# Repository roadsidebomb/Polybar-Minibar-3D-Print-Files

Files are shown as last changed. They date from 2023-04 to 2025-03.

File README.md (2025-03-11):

<br/>
<div align="center">
Polybar & Minibar
</div>

# Polybar & Minibar
**3D Printable Music Game Controllers!**

The Polybar project, by 3PCS (threepieces), is a modular 3D printable controller for music games like YARG, Clone Hero, or similar.
  
You can find the latest version under [releases](https://github.com/roadsidebomb/Polybar-Minibar-3D-Print-Files/releases). The download includes all STL, F3D and PCB files for use under the license listed below.

## 🎧 Discord 

<p>Join us on Discord! https://discord.gg/rRTbyKxyRu<br /> 
If you have questions regarding downloads, editing of files or need help with assembling your controller, drop us a line. We won't bite!</p>

## 🔨 Contributing

<p>Contributions are always welcome!<br /> 
If you have ideas for a new project, or existing ones, feel free to add roadsidebomb#7604 on Discord to get in touch on how to get involved.</p>

## 💎 License

<p>This project utilizes the Attribution-NonCommercial-ShareAlike 4.0 International (CC BY-NC-SA 4.0) license.<br /> 
https://creativecommons.org/licenses/by-nc-sa/4.0/<br /> 
You are free to:<br /> 
Share — copy and redistribute the material in any medium or format<br /> 
Adapt — remix, transform, and build upon the material<br /> 
Under no circumstances are you allowed to use any of the provided materials for commercial works, unless given permission by the owner.</p>

## 💸 Donate

<p>You can donate to 3PCS, and support projects like this, and future projects at the link below!<br /> 
https://ko-fi.com/threepcs</p>

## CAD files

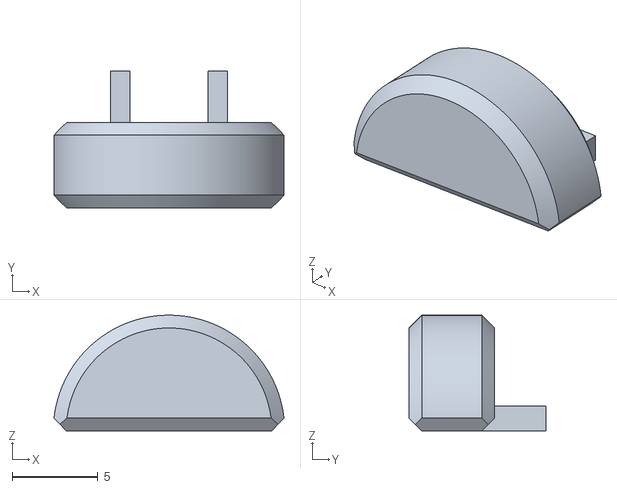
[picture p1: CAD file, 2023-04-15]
Official Releases/Polybar-Minibar v5.0 STLs/Alternates/1. Kailh Choc Fret Insert/Kailh Choc Fret Insert - .25 down.stl
13.4 x 8.00 x 6.75

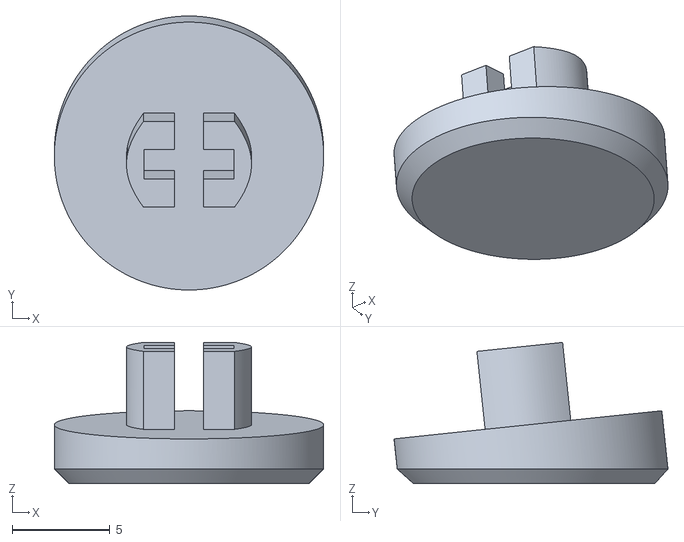
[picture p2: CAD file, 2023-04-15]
Official Releases/Polybar-Minibar v5.0 STLs/Alternates/2. MX Cherry Fret Insert/MX Cherry Fret Insert - .5 down.stl
13.8 x 14.0 x 7.21

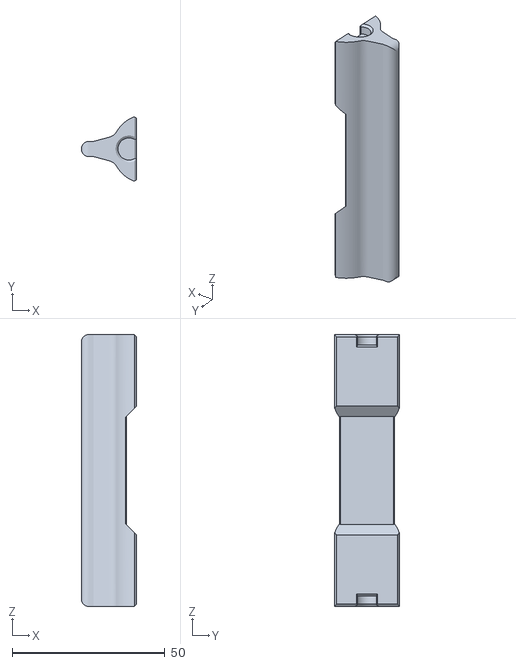
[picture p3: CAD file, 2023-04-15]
Official Releases/Polybar-Minibar v5.0 STLs/Alternates/3. Large Strum Bar/Large Strum Bar - 1 up.stl
18.1 x 21.1 x 89.0

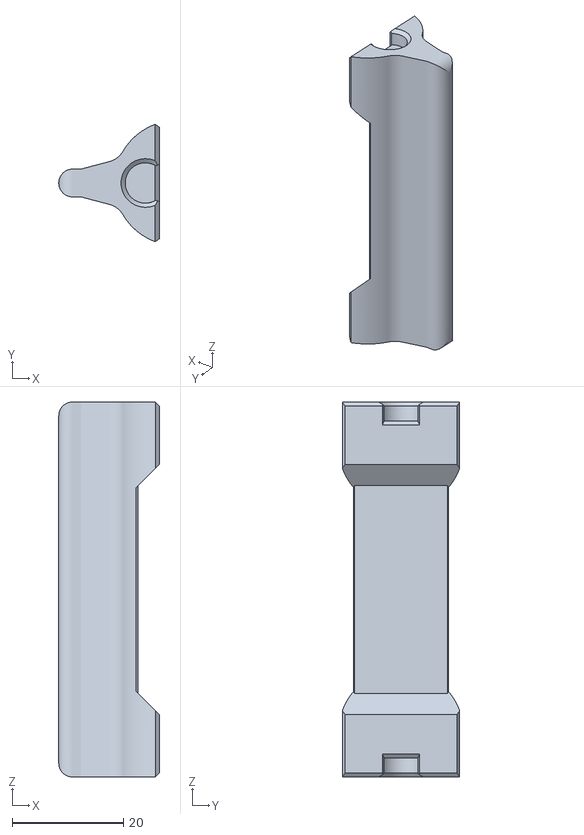
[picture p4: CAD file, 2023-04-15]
Official Releases/Polybar-Minibar v5.0 STLs/Alternates/4. Small Strum Bar/Small Strum Bar - .5 up.stl
18.1 x 21.1 x 67.5

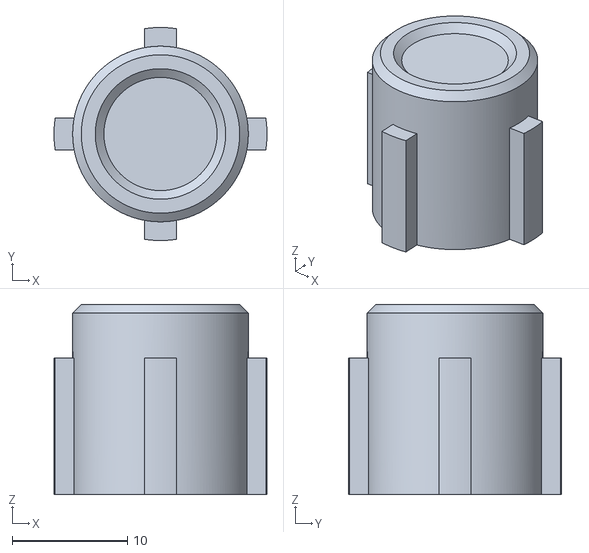
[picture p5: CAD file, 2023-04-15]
Official Releases/Polybar-Minibar v5.0 STLs/Alternates/5. Large Button/Large Button - .375 down.stl
18.5 x 18.5 x 16.5

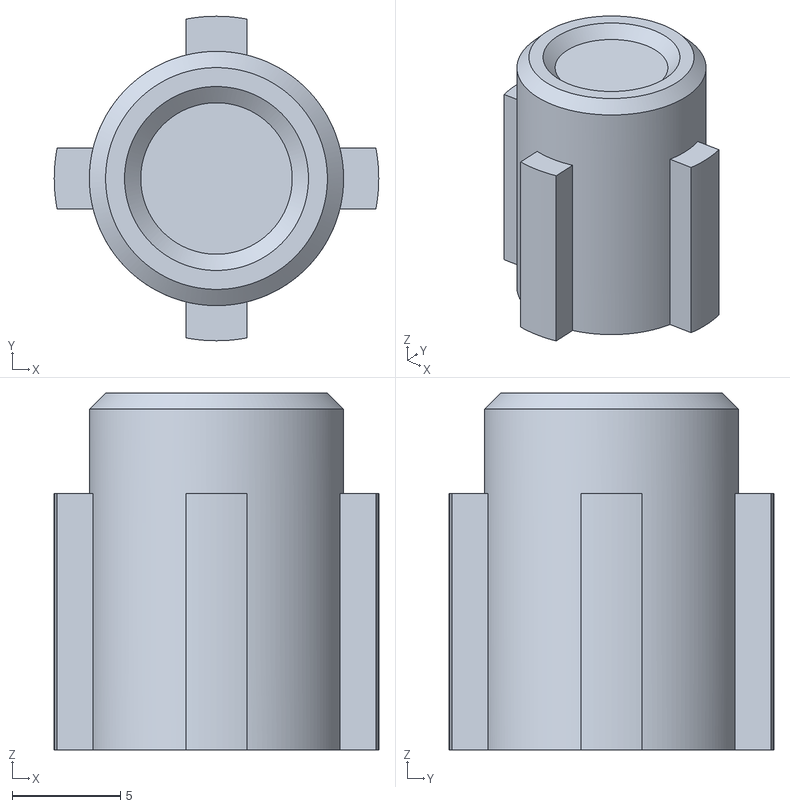
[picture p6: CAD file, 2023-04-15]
Official Releases/Polybar-Minibar v5.0 STLs/Alternates/6. Small Button/Small Button - .375 down.stl
15.0 x 15.0 x 16.5

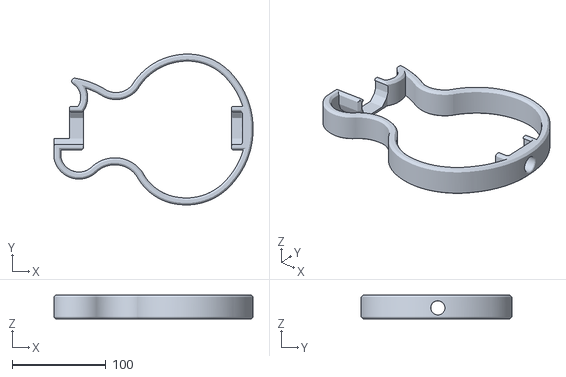
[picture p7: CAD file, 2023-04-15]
Official Releases/Polybar-Minibar v5.0 STLs/Frames/Minibar Les Paul Frame.stl
212.5 x 161.1 x 25.5

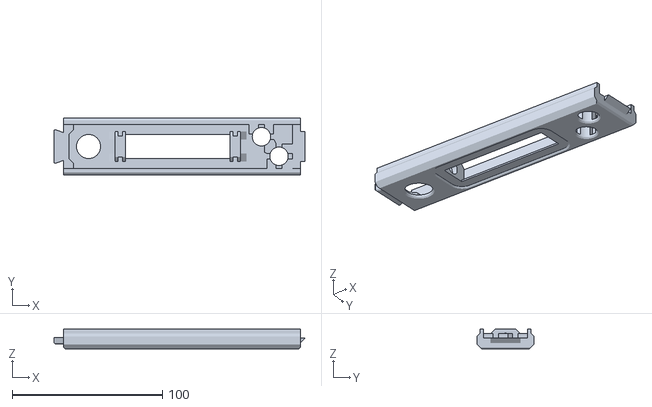
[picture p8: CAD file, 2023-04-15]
Official Releases/Polybar-Minibar v5.0 STLs/Minibar/Minibar Strum Case (Top).stl
166.9 x 38.0 x 13.0

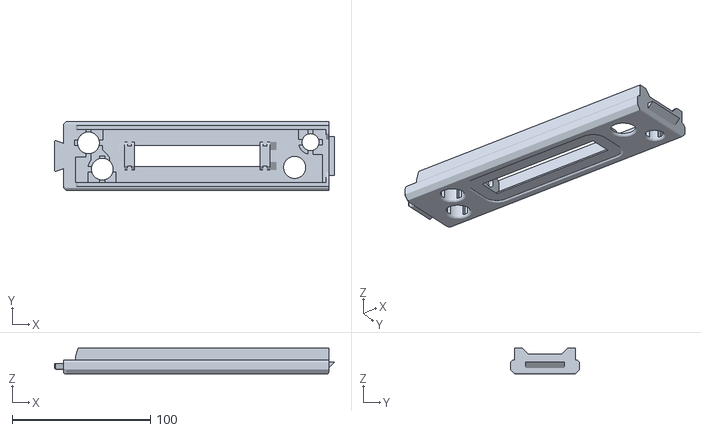
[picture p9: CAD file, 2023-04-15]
Official Releases/Polybar-Minibar v5.0 STLs/Polybar/Polybar Strum Case (Top).stl
202.7 x 50.0 x 18.5

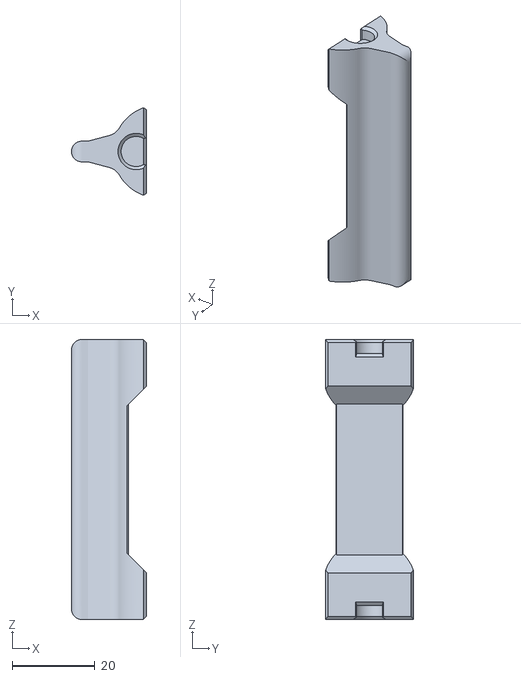
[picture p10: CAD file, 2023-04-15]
Official Releases/Polybar-Minibar v5.0 STLs/Universal Parts/Small Strum Bar.stl
18.1 x 21.1 x 67.5

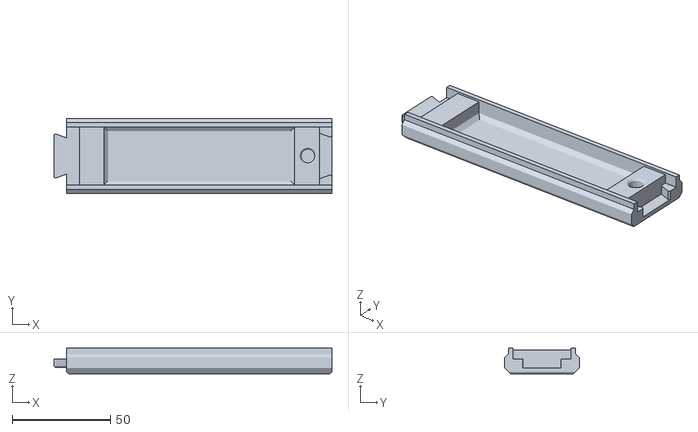
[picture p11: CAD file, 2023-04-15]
Official Releases/Polybar-Minibar v5.0 STLs/Universal Shells/Long Extension (Top).stl
141.4 x 38.0 x 13.0

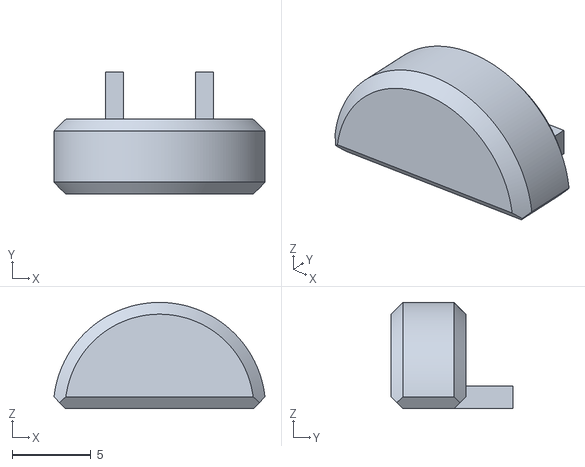
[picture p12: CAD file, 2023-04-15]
Official Releases/Polybar-Minibar v5.0 STLs/Alternates/1. Kailh Choc Fret Insert/Kailh Choc Fret Insert - .5 down.stl
13.4 x 7.75 x 6.75

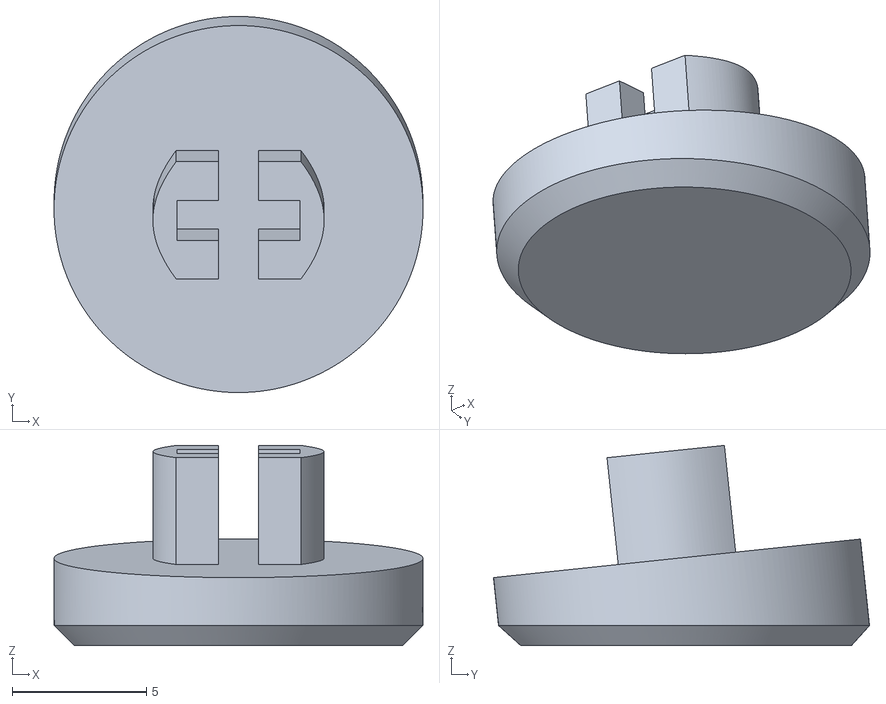
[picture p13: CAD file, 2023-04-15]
Official Releases/Polybar-Minibar v5.0 STLs/Alternates/2. MX Cherry Fret Insert/MX Cherry Fret Insert - .25 down.stl
13.7 x 14.0 x 7.46

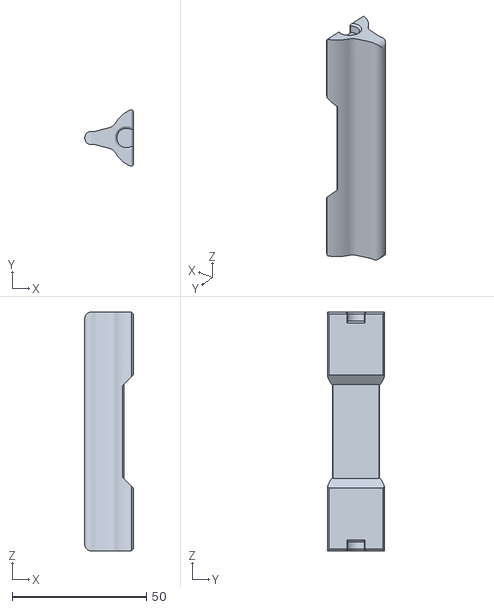
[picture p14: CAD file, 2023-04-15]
Official Releases/Polybar-Minibar v5.0 STLs/Alternates/3. Large Strum Bar/Large Strum Bar - .75 up.stl
18.1 x 21.1 x 89.0

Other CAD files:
Official Releases/Polybar-Minibar v5.0 STLs/Alternates/4. Small Strum Bar/Small Strum Bar - .25 up.stl
Official Releases/Polybar-Minibar v5.0 STLs/Alternates/5. Large Button/Large Button - .5 down.stl
Official Releases/Polybar-Minibar v5.0 STLs/Alternates/6. Small Button/Small Button - .5 down.stl
Official Releases/Polybar-Minibar v5.0 STLs/Frames/Polybar Les Paul Frame (Bottom).stl
Official Releases/Polybar-Minibar v5.0 STLs/Alternates/3. Large Strum Bar/Large Strum Bar - .25 up.stl
Official Releases/Polybar-Minibar v5.0 STLs/Alternates/3. Large Strum Bar/Large Strum Bar - .5 up.stl
Official Releases/Polybar-Minibar v5.0 STLs/Alternates/4. Small Strum Bar/Small Strum Bar - .75 up.stl
Official Releases/Polybar-Minibar v5.0 STLs/Alternates/4. Small Strum Bar/Small Strum Bar - 1 up.stl
Official Releases/Polybar-Minibar v5.0 STLs/Alternates/5. Large Button/Large Button - .125 down.stl
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

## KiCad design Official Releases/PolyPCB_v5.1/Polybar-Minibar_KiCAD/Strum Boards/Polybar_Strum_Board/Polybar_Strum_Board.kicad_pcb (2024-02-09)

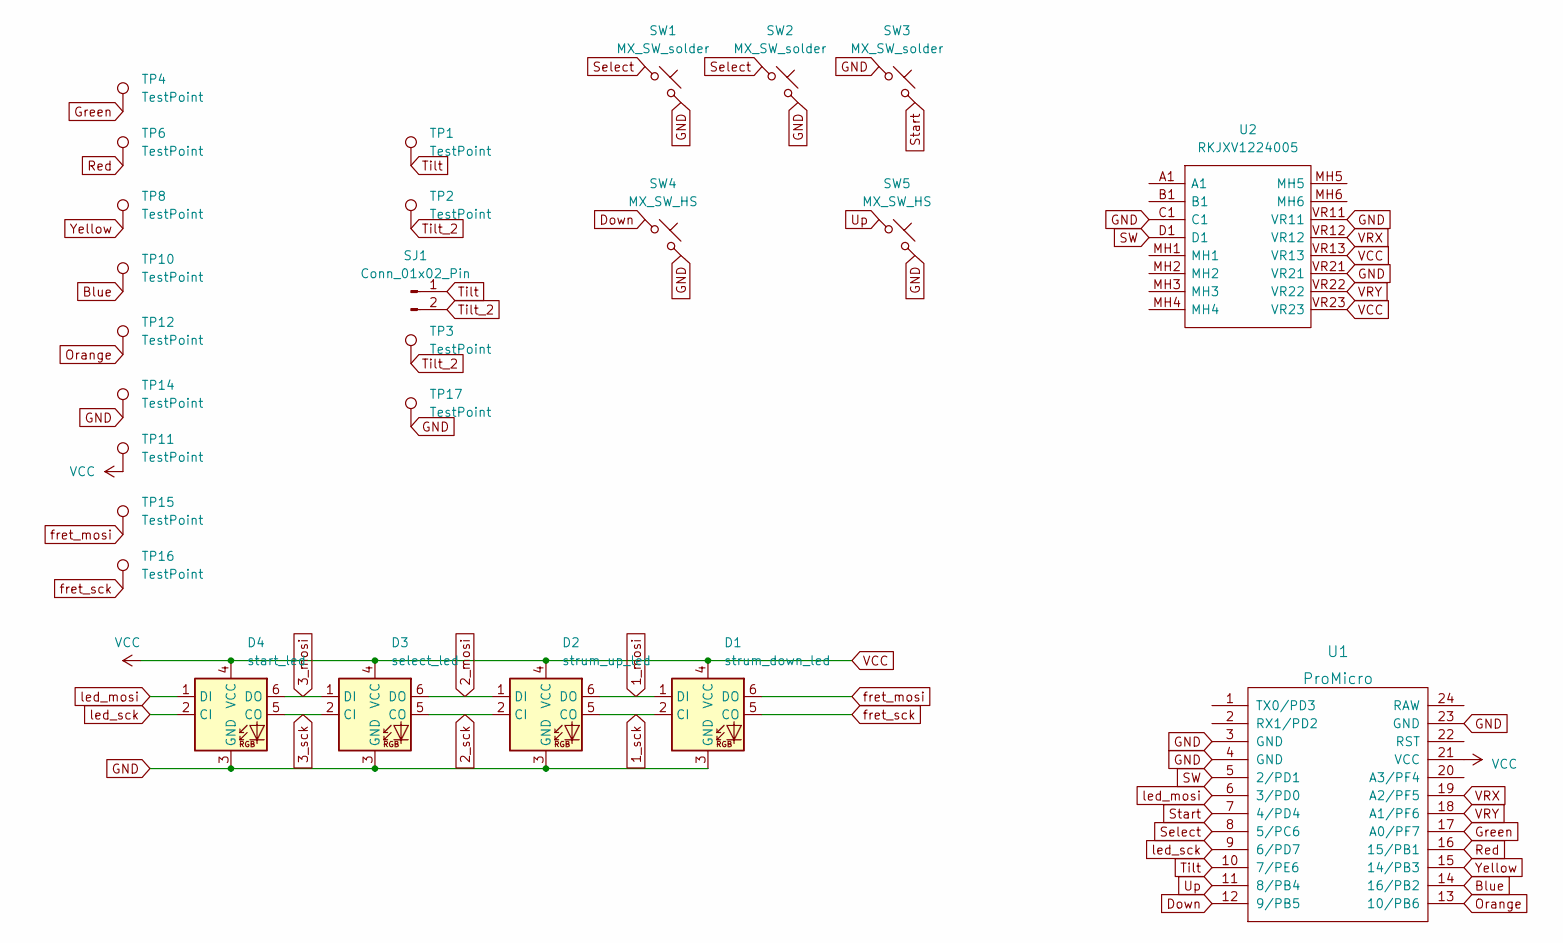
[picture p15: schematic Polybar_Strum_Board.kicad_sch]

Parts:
D1: strum_down_led; LED_RGB_5050-6
D2: strum_up_led; LED_RGB_5050-6
D3: select_led; LED_RGB_5050-6
D4: start_led; LED_RGB_5050-6
SJ1: Conn_01x02_Pin; Solder_Jumper
SW1, SW2, SW3: MX_SW_solder; SW_SPST_PTS645
SW4, SW5: MX_SW_HS; Kailh_Hotswap_MX
TP1, TP2, TP3, TP17: TestPoint; test_point_2
TP4, TP6, TP8, TP10, TP11, TP12, TP14, TP15, TP16: TestPoint; test_point
U1: ProMicro; KB2040-ProMicroPins
U2: RKJXV1224005; Manufacturer_Part_Number RKJXV1224005; Mouser Part Number 688-RKJXV1224005

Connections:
1_mosi: D1.1 (DI), D2.6 (DO)
1_sck: D1.2 (CI), D2.5 (CO)
2_mosi: D2.1 (DI), D3.6 (DO)
2_sck: D2.2 (CI), D3.5 (CO)
3_mosi: D3.1 (DI), D4.6 (DO)
3_sck: D3.2 (CI), D4.5 (CO)
Blue: TP10.1, U1.14 (16/PB2)
Down: SW4.1, U1.12 (9/PB5)
GND: D1.3 (GND), D2.3 (GND), D3.3 (GND), D4.3 (GND), SW1.2, SW2.2, SW3.1, SW4.2, SW5.2, TP14.1, TP17.1, U1.3 (GND), U1.4 (GND), U1.23 (GND), U2.C1, U2.VR11, U2.VR21
Green: TP4.1, U1.17 (A0/PF7)
Orange: TP12.1, U1.13 (10/PB6)
Red: TP6.1, U1.16 (15/PB1)
SW: U1.5 (2/PD1), U2.D1
Select: SW1.1, SW2.1, U1.8 (5/PC6)
Start: SW3.2, U1.7 (4/PD4)
Tilt: SJ1.1, TP1.1, U1.10 (7/PE6)
Tilt_2: SJ1.2, TP2.1, TP3.1
Up: SW5.1, U1.11 (8/PB4)
VCC: D1.4 (VCC), D2.4 (VCC), D3.4 (VCC), D4.4 (VCC), TP11.1, U1.21 (VCC), U2.VR13, U2.VR23
VRX: U1.19 (A2/PF5), U2.VR12
VRY: U1.18 (A1/PF6), U2.VR22
Yellow: TP8.1, U1.15 (14/PB3)
fret_mosi: D1.6 (DO), TP15.1
fret_sck: D1.5 (CO), TP16.1
led_mosi: D4.1 (DI), U1.6 (3/PD0)
led_sck: D4.2 (CI), U1.9 (6/PD7)

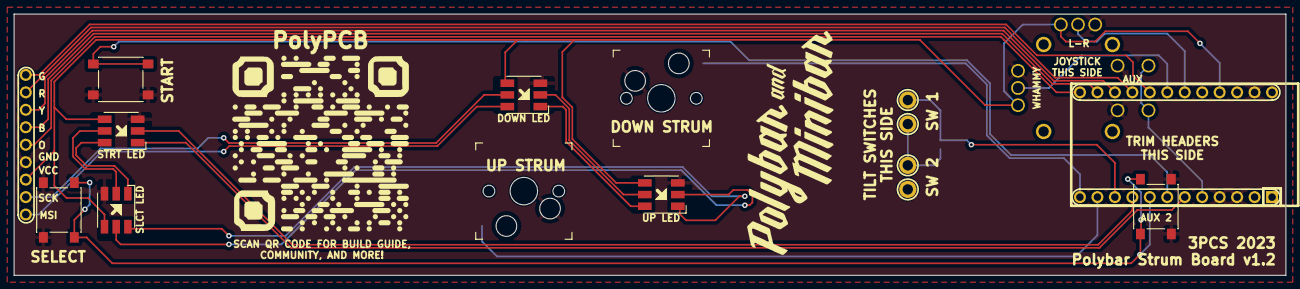
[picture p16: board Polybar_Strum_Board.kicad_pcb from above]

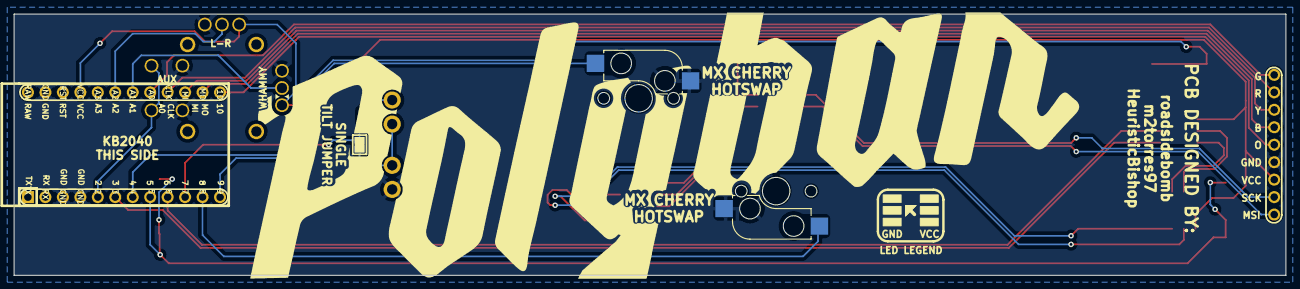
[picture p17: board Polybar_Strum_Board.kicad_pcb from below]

Board: 2 copper layers, 185.0 x 38.0 mm, 25 parts (2 on the bottom side), 26 nets.

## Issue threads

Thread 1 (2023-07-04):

Non-Discord documentation

Soundtoxin, 2023-07-04:
Hello, this might not go over well, but I don't use Discord or ever plan to use it due to many issues with it from it being proprietary, centralized, often censored, banning of people randomly, deleting of old stuff on there, etc.
I see you link the Discord all over, and normally when I see that in a project I try my best to ignore it and do what I can without going in there, but from what I've gathered, the instructions to actually build this thing are locked behind Discord. I was hoping to get into YARG and similar stuff soon. I just fixed the strum bar on an old Wii Guitar Hero World Tour controller I had around, and was getting annoyed by stuff like overstrum when playing some Rock Band with it, so I started looking into possibly making my own controller. Polybar looks awesome, and I've built other projects like DIY mechanical keyboard builds, Flatbox rev5, Open-Frame1, etc. that have some similiarities in how they use keyboard switches and microcontrollers. I grabbed the files off of Printables, but there is a *lot* here, I'm not sure if I'll be able to figure it out without the proper documentation.
It would be amazing if you could put up the guide elsewhere. Either a dedicated website for the project or maybe on a GitHub page somewhere. It's a real shame to see information locked behind Discord, and likely to be lost someday because of it as well. If you could get it out on the web, it could have backups on Archive.org as well, improving the longevity of this amazing work you've done. I really hope you'll consider posting all the necessary info somewhere besides Discord. There really are some of us out there that would appreciate it.

Soundtoxin, 2023-07-04:
It looks like I'll need to get the files for the PCBs as well. Those should also definitely just be on GitHub in their own repo or something, like what [Flatbox](https://github.com/jfedor2/flatbox) and [Open-Frame1](https://github.com/GregTurbo/Open-Frame1) do with theirs.

Soundtoxin, 2023-07-05:
My bad, I see the release archives here actually contain more than just the stuff on printables. I was thinking this was just the STLs again.

Closed 2023-07-05.

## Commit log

2024-02-09 extracted all KiCad files
    [Cherry_MX_Fret_Board.kicad_pcb, Cherry_MX_Fret_Board.kicad_sch, Kailh_Choc_Fret_Board.kicad_pcb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]
2024-02-09 deleted the KiCad .zip file
2024-02-09 Extracted KiCad .zip file
    [Cherry_MX_Fret_Board.kicad_pcb, Cherry_MX_Fret_Board.kicad_sch, Kailh_Choc_Fret_Board.kicad_pcb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]
2024-02-09 Deleted KiCad .zip file
2024-02-09 Linked everything in the PCB to the schematic
    [Polybar_Strum_Board.kicad_pcb, Polybar_Strum_Board.kicad_sch]
2024-02-10 removed misnamed files
    [Cherry_MX_Fret_Board.kicad_pcb, Cherry_MX_Fret_Board.kicad_sch, Kailh_Choc_Fret_Board.kicad_pcb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]
